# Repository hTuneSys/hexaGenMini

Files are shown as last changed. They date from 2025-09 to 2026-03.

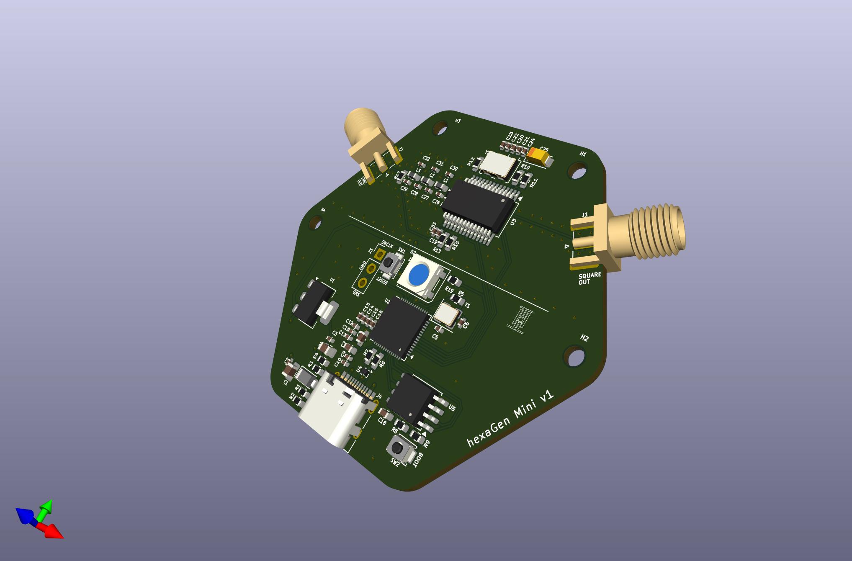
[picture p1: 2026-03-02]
hardware/hexaGenMini-v1/hexaGenMini-v1-2.jpg

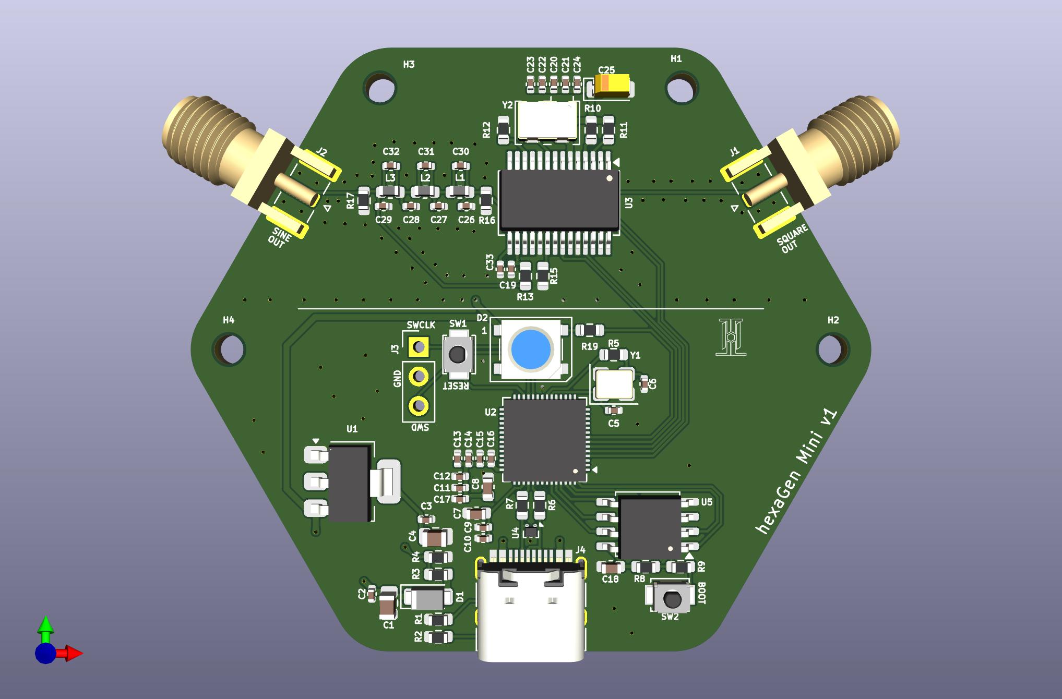
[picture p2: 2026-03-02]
hardware/hexaGenMini-v1/hexaGenMini-v1-1.jpg

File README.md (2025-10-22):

<!--
SPDX-FileCopyrightText: 2025 hexaTune LLC
SPDX-License-Identifier: MIT
-->

# 🎛️ hexaGenMini






**hexaGenMini** is a compact, USB-powered signal generator designed for music synthesis and electronic experimentation. Built on the Raspberry Pi Pico (RP2040), it features Direct Digital Synthesis (DDS) for precise frequency generation, RGB status indication, and USB MIDI control via AT commands.

Developed by **hexaTune LLC** and the **hexaTeam**, led by **Husamettin ARABACI**.

## ✨ Features

- **Precise Frequency Generation**: AD985x DDS chip supporting frequencies up to 125MHz
- **USB MIDI Control**: Send AT commands via MIDI SysEx for remote control
- **RGB Status LED**: Visual feedback for device state and DDS availability
- **Firmware Updates**: Built-in BOOTSEL mode for easy firmware flashing
- **Cross-Platform**: Works with any USB MIDI-compatible host
- **Mobile App**: Control via dedicated iOS/Android app ([hexaGenApp](https://github.com/hTuneSys/hexaGenApp))
- **Open Source**: Fully open hardware and software under MIT license

## 📱 Mobile App

Control your hexaGenMini wirelessly with our companion mobile app:

- **iOS & Android Support**
- **Real-time Frequency Control**
- **Preset Management**
- **Visual Waveform Display**




**Source Code**: [hTuneSys/hexaGenApp](https://github.com/hTuneSys/hexaGenApp)

## 🚀 Quick Start

1. **Connect** your hexaGenMini via USB
2. **Flash Firmware**:
   ```bash
   cd firmware
   cargo run
   ```
3. **Send AT Commands** via MIDI SysEx:
   ```
   AT+FREQ=1#1000000#1000  # Set 1MHz for 1 second
   AT+SETRGB=2#255#0#128   # Set LED to purple
   ```

## 📦 Installation

### Prerequisites

- **Rust** (1.86.0+): [Install rustup](https://rustup.rs/)
- **picotool**: For flashing RP2040
- **Node.js & pnpm**: For development tools
- **KiCad** (optional): For hardware modifications
- **FreeCAD** (optional): For enclosure modifications

### Setup

```bash
# Clone repository
git clone https://github.com/hTuneSys/hexaGenMini.git
cd hexaGenMini

# Install development dependencies
pnpm install
pnpm prepare  # Setup husky pre-commit hooks

# Install Rust targets
rustup target add thumbv6m-none-eabi
```

### Flashing Firmware

```bash
cd firmware
cargo run
```

Put your device in BOOTSEL mode (hold BOOTSEL while plugging in) when prompted.

## 🎯 Usage

### AT Command Protocol

hexaGenMini uses AT commands sent via MIDI SysEx messages:

#### Supported Commands

- `AT+VERSION?` - Get firmware version
- `AT+SETRGB=<ID>#<R>#<G>#<B>` - Set RGB LED color
- `AT+FREQ=<ID>#<FREQ>#<TIME_MS>` - Generate frequency with dwell time
- `AT+RESET=<ID>` - System reset
- `AT+FWUPDATE=<ID>` - Enter firmware update mode

#### Example Usage

```bash
# Query version
AT+VERSION?

# Set frequency to 440Hz for 5 seconds
AT+FREQ=1#440#5000

# Set LED to red
AT+SETRGB=2#255#0#0
```

### Hardware Connections

- **USB**: Power and MIDI communication
- **SMA Output**: DDS signal output
- **RGB LED**: Status indication
- **BOOTSEL**: Firmware update mode

## 🏗️ Architecture

The firmware is built with Rust and Embassy, running concurrent async tasks:

- **USB Task**: MIDI communication handling
- **AT Dispatcher**: Command parsing and routing
- **DDS Task**: Frequency generation control
- **RGB Task**: LED management
- **Main Loop**: Status monitoring

For detailed architecture information, see [docs/ARCHITECTURE.md](docs/ARCHITECTURE.md).

## 📁 Project Structure

```
hexaGenMini/
├── firmware/          # Rust firmware (Embassy framework)
├── hardware/          # KiCad PCB designs
├── mechanic/          # FreeCAD enclosure designs
├── docs/             # Documentation
├── .github/          # CI/CD workflows
└── README.md
```

## 🤝 Contributing

We welcome contributions! Please see our [Contributing Guide](docs/CONTRIBUTING.md) for details.

### Development Workflow

1. Fork the repository
2. Create a feature branch from `develop`
3. Make your changes
4. Submit a pull request
5. Follow conventional commit format

### Areas for Contribution

- Firmware enhancements
- Hardware improvements
- Documentation
- Mobile app features
- Testing and CI/CD

## 📄 Documentation

- [Getting Started](docs/GETTING_STARTED.md) - Setup guide
- [Architecture](docs/ARCHITECTURE.md) - System design
- [Project Structure](docs/PROJECT_STRUCTURE.md) - Repository overview
- [Contributing](docs/CONTRIBUTING.md) - How to contribute
- [FAQ](docs/FAQ.md) - Common questions

## 📜 License

This project is licensed under the MIT License - see the [LICENSE](LICENSE) file for details.

## 📞 Contact

- **Website**: [hexatune.com](https://hexatune.com)
- **Email**: [info@hexatune.com](mailto:info@hexatune.com)
- **GitHub**: [hTuneSys](https://github.com/hTuneSys)
- **Issues**: [GitHub Issues](https://github.com/hTuneSys/hexaGenMini/issues)

## 🙏 Acknowledgments

Built with ❤️ by the hexaTeam at hexaTune LLC.

Special thanks to the Rust embedded community and Embassy framework developers.

---

**hexaGenMini** - Precision meets portability in signal generation.

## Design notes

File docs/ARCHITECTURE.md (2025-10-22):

<!--
SPDX-FileCopyrightText: 2025 hexaTune LLC
SPDX-License-Identifier: MIT
-->

# 🏗️ hexaGenMini Architecture

---

## 📬 Questions?

Contact the team at **[info@hexatune.com](mailto:info@hexatune.com)** or open an issue.

---

Built by [hexaTune LLC](https://hexatune.com) · GitHub: [hTuneSys/hexaGenMini](https://github.com/hTuneSys/hexaGenMini) · License: [MIT](https://opensource.org/license/mit/)

---

## Overview

hexaGenMini is a compact signal generator device based on the Raspberry Pi Pico (RP2040) microcontroller. It features a Direct Digital Synthesis (DDS) module for generating precise waveforms, an RGB LED for status indication, and USB MIDI communication for control. The device is designed for integration into music synthesis setups, providing frequency generation capabilities via AT command protocol over MIDI SysEx messages.

## System Architecture

The firmware is written in Rust using the Embassy framework for embedded async programming. It consists of several modules running as concurrent tasks on the RP2040's dual cores:

- **USB Module**: Handles USB MIDI communication
- **AT Command Module**: Parses and dispatches AT commands
- **DDS Module**: Controls the AD985x DDS chip for frequency generation
- **RGB Module**: Manages the WS2812 RGB LED
- **Channel Manager**: Facilitates inter-task communication via async channels

### Core 0 Tasks
- USB Device Task
- USB IO Task
- AT Task
- RGB Task
- Main Loop Task

### Core 1 Tasks
- DDS Task

## System Flow

1. **Initialization**: The main function initializes peripherals, sets up channels, and spawns tasks on both cores.

2. **USB Communication**: USB IO task listens for incoming MIDI packets containing SysEx messages.

3. **AT Command Parsing**: Received SysEx payloads are parsed into AT commands.

4. **Command Dispatch**: The AT dispatcher routes commands to appropriate handlers based on the command name.

5. **Handler Execution**: Handlers perform actions like setting frequency, changing LED color, or triggering firmware updates.

6. **Response Generation**: Results are compiled back into AT response format and sent via USB MIDI.

## AT Command Structure

AT commands follow a specific format for communication with the device:

### Command Format
```
AT+<COMMAND>=<ID>#<PARAM1>#<PARAM2>#...
```

### Query Format
```
AT+<COMMAND>?
```

### Response Format
```
AT+<RESPONSE>=<ID>#<PARAM1>#<PARAM2>#...
```

### Supported Commands

#### VERSION
- **Query**: `AT+VERSION?`
- **Response**: `AT+VERSION=0#v1.0.0`
- **Description**: Returns the firmware version

#### SETRGB
- **Command**: `AT+SETRGB=<ID>#<R>#<G>#<B>`
- **Response**: `AT+DONE=<ID>`
- **Description**: Sets the RGB LED color (R, G, B values 0-255)
- **Example**: `AT+SETRGB=123#255#0#128`

#### RESET
- **Command**: `AT+RESET=<ID>`
- **Description**: Performs a system reset
- **Note**: No response as device resets

#### FWUPDATE
- **Command**: `AT+FWUPDATE=<ID>`
- **Description**: Enters BOOTSEL mode for firmware update
- **Note**: No response as device enters bootloader

#### FREQ
- **Command**: `AT+FREQ=<ID>#<FREQUENCY>#<TIME_MS>`
- **Response**: `AT+DONE=<ID>` or `AT+ERROR=<ID>#<ERROR_CODE>`
- **Description**: Sets DDS frequency with dwell time
- **Parameters**:
  - FREQUENCY: Frequency in Hz (u32)
  - TIME_MS: Dwell time in milliseconds (u32)
- **Example**: `AT+FREQ=456#1000000#5000`

### Error Codes
- E001001: Invalid command
- E001002: DDS busy
- E001003: Invalid UTF-8
- E001004: Invalid SysEx
- E001005: Invalid data length
- E001006: Parameter count error
- E001007: Parameter value error
- E001008: Not a query
- E001009: Unknown command

## Communication Protocol

Commands are sent as MIDI SysEx messages over USB MIDI:

- **SysEx Start**: 0xF0
- **Payload**: UTF-8 encoded AT command string
- **SysEx End**: 0xF7

The USB MIDI implementation uses standard MIDI packet formats for SysEx transmission.

## Hardware Interfaces

- **USB**: Full-speed USB 2.0 for MIDI communication
- **DDS**: AD985x controlled via GPIO bit-banging
- **RGB LED**: WS2812 controlled via PIO
- **Status LED**: Onboard LED for system status

## Task Communication

Inter-task communication uses Embassy async channels with a capacity of 16 messages per channel. The ChannelManager provides typed access to senders and receivers for each module.

## Configuration

System configuration is managed through constants in `hexa_config` module, including version information and DDS availability status.

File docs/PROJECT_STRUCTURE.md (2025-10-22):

<!--
SPDX-FileCopyrightText: 2025 hexaTune LLC
SPDX-License-Identifier: MIT
-->

# 📁 Project Structure: `hexaGenMini`

This document outlines the organization of the hexaGenMini project repository.

## Root Directory

- `.github/`: GitHub workflows, issue templates, and configuration
- `.husky/`: Git hooks for commit linting
- `docs/`: Documentation files
- `firmware/`: Embedded firmware source code (Rust)
- `hardware/`: PCB design files (KiCad)
- `mechanic/`: Mechanical design files (FreeCAD)
- `LICENSE`: MIT license
- `README.md`: Project overview
- `package.json` & `pnpm-lock.yaml`: Node.js dependencies for tooling

## Firmware Directory (`firmware/`)

The firmware is written in Rust using the Embassy framework for the RP2040 microcontroller.

- `src/`: Source code
  - `main.rs`: Application entry point and task initialization
  - `at/`: AT command parsing and handling
  - `channel/`: Inter-task communication channels
  - `dds/`: Direct Digital Synthesis (AD985x) control
  - `error/`: Error definitions
  - `hexa_config/`: Configuration constants
  - `rgb/`: RGB LED control
  - `sysex/`: MIDI SysEx message handling
  - `usb/`: USB MIDI communication
- `build.rs`: Build script for memory layout
- `Cargo.toml`: Rust dependencies and build configuration
- `memory.x`: Linker memory layout

## Hardware Directory (`hardware/`)

PCB designs created with KiCad.

- `hexaGenMini-v1/`: Main PCB design
  - `fabrication_output/`: Manufacturing files
    - `bom/`: Bill of Materials
    - `gerber/`: Gerber files for PCB fabrication
    - `pnp/`: Pick and place files
  - `*.kicad_*`: KiCad project files
  - `PCB_Library.pretty/`: Custom KiCad footprints
  - `SCH_Library.kicad_sym`: Custom KiCad symbols

## Mechanic Directory (`mechanic/`)

Mechanical designs for the product enclosure, created with FreeCAD.

- `Bottom.FCStd`: Bottom case design
- `PcbBoard.FCStd`: PCB mounting design
- `PcbBoard-Body.dxf`: 2D export for manufacturing

## Documentation (`docs/`)

- `ARCHITECTURE.md`: System architecture and AT command protocol
- `BRANCH_STRATEGY.md`: Git branching guidelines
- `BRANDING.md`: Branding guidelines
- `COMMIT_STRATEGY.md`: Commit message conventions
- `COMMUNITY.md`: Community guidelines
- `CONFIGURATION.md`: Configuration instructions
- `CONTACT.md`: Contact information
- `CONTRIBUTING.md`: Contribution guidelines
- `DEVELOPMENT_GUIDE.md`: Development setup
- `FAQ.md`: Frequently asked questions
- `GETTING_STARTED.md`: Quick start guide
- `LABELLING_STRATEGY.md`: Issue labeling
- `PR_STRATEGY.md`: Pull request guidelines
- `PROJECT_BOARD.md`: Project management
- `PROJECT_STRUCTURE.md`: This file
- `SECURITY.md`: Security policy
- `STYLE_GUIDE.md`: Code style guidelines
- `SUMMARY.md`: Project summary
- `SUPPORT.md`: Support information

## Build and Development

- Firmware: Built with Cargo (Rust toolchain)
- Hardware: Fabricated using standard PCB processes
- Mechanics: Manufactured using 3D printing or CNC

For detailed setup instructions, see `docs/DEVELOPMENT_GUIDE.md`.

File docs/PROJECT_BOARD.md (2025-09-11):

<!--
SPDX-FileCopyrightText: 2025 hexaTune LLC
SPDX-License-Identifier: MIT
-->

# PROJECT_BOARD.md

This document describes the structure and usage of the hexaGenMini GitHub Project Board used for tracking issues, workflows, and development progress.

---

## 🧭 Board Overview

The hexaGenMini project board is organized using GitHub Projects (v2) with the following columns:

1. **Inbox** – New issues or ideas needing triage  
2. **Backlog** – Approved but not yet scheduled items  
3. **In Progress** – Actively being worked on  
4. **In Review** – Awaiting PR review or discussion  
5. **Blocked** – Work paused due to dependencies  
6. **Done** – Completed tasks  
7. **Closed** – Rejected or archived items  

---

## 🏷️ Label Integration

Cards are automatically categorized using GitHub Labels, such as:

- `type: bug`, `type: feature`, `type: question`, etc.
- `status: in progress`, `status: review`, `status: blocked`
- `priority: high`, `priority: low`

These labels help sort and filter cards efficiently.

---

## 🔄 Workflow Rules

- Issues moved to **In Progress** must be assigned to a contributor.
- Pull Requests are linked to issues and automatically update board state.
- The **In Review** column is for PRs with open reviews.
- Cards in **Done** are periodically cleaned up to **Closed**.

---

## 🔧 Automation

GitHub Actions and project workflows automate the board:

- Auto-assign labels on issue creation
- Auto-move cards based on PR status
- Auto-close completed issues when PRs are merged

---

## 🔗 Access the Board

Visit the live project board here:  
➡️ [BOARD](https://github.com/orgs/hTuneSys/projects/16/views/1)

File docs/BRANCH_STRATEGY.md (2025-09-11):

<!--
SPDX-FileCopyrightText: 2025 hexaTune LLC
SPDX-License-Identifier: MIT
-->

# 📚 Branching Strategy for hexaGenMini

This project follows a structured, scalable branching model inspired by GitHub Flow, Gitflow, and real-world enterprise project practices.  
All contributors are expected to adhere to these rules for consistent development and stable releases.

---

## 🔱 Branch Layers and Types

| Branch | Purpose | Allowed Types (Prefix) |
|---|---|---|
| `main` | Production branch. All official releases are tagged here. | N/A (protected branch) |
| `release/x.y` | Pre-release stabilization, final QA and testing. | N/A (protected branch) |
| `develop` | Integration branch for ongoing feature and fix PRs. | N/A (protected branch) |
| `feature/xyz` | Development of new features. | `feat/` |
| `fix/bug-id` | Bug fixes and patches. | `fix/` |
| `chore/*` | Routine tasks, maintenance, housekeeping. | `chore/` |
| `refactor/*` | Code refactoring without feature or bug changes. | `refactor/` |
| `test/*` | Test additions and modifications. | `test/` |
| `docs/*` | Documentation improvements and additions. | `docs/` |
| `ci/*` | Continuous Integration and automation scripts. | `ci/` |
| `perf/*` | Performance improvements. | `perf/` |
| `build/*` | Build-related changes (packaging, dependencies). | `build/` |
| `hotfix/*` | Emergency fixes applied directly on `main`. | `hotfix/` |
| `style/*` | Code style and formatting changes. | `style/` |

---

## 🔄 Pull Request Flow

### 🔁 For Contributors

- All PRs **must be based on `develop`** unless hotfixing `main`.
- Branch names should start with one of the allowed prefixes from the table above.
- PR titles must follow [Conventional Commits](https://www.conventionalcommits.org/) format.
- Keep your PR focused and small for easier review.

### ✅ Merge Rules

- `feature/*`, `fix/*`, `chore/*`, `refactor/*`, `test/*`, `docs/*`, `ci/*`, `perf/*`, `build/*`, `style/*` → merge into `develop` after review & CI pass.
- `develop` → `release/x.y` at sprint end for release prep.
- `release/x.y` → `main` after QA and approval.
- `hotfix/*` → `main` → `develop` immediately.

---

## 🔐 Branch Protection Rules

| Branch | Protection |
|---|---|
| `main` | Required PR, review, status checks |
| `release/*`  | Only maintainers can merge |
| `develop` | PR required, minimum 1 review |
| others | No restriction, delete after merge |

---

## 🗓️ Merge Schedule

| Action | Frequency |
|---|---|
| `feature/*` → `develop` | As soon as ready |
| `develop` → `release/x.y` | Weekly or per sprint |
| `release/x.y` → `main` | After QA/approval |
| `hotfix/*` → `main` | Immediately if needed|

---

## 🧹 Cleanup Policy

- Merged feature, fix, chore, refactor, test, docs, ci, perf, build, style branches **must be deleted immediately**.
- `release/*` branches are deleted **after tagging**.
- `hotfix/*` branches are merged and deleted **immediately**.
- Consider automating branch deletion using GitHub Settings or scripts.

---

## 📈 Do’s and Don’ts

### Do

- Use **clear, descriptive branch names** with allowed prefixes.
- Open **small, focused PRs** for faster review.
- Follow **commit and PR title conventions**.
- Sync with `develop` frequently.

### Don’t

- Push large or unrelated changes in a single PR.
- Merge into `main` or `release/*` without approval.
- Use branch names outside the approved prefixes.
- Forget to delete branches after merge.

---

## 🔄 PR Flow Diagram (Textual)

```text
feature/*, fix/*, chore/* ... -> develop -> release/x.y -> main
                                ↑               ↑
                           hotfix/* ------------|
```

---

## 📬 Questions?

If you have questions or need help, open a discussion at:  
[https://github.com/hTuneSys/hexaGenMini/discussions](https://github.com/hTuneSys/hexaGenMini/discussions)

---

> Maintained by @husamettinarabaci · hexaTune LLC

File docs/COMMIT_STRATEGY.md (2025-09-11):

<!--
SPDX-FileCopyrightText: 2025 hexaTune LLC
SPDX-License-Identifier: MIT
-->

# COMMIT_STRATEGY.md

## 🔖 Commit Message Strategy for hexaGenMini

To ensure consistent and readable commit messages across the project, **hexaGenMini** enforces the use of a standardized commit format and a predefined set of commit types.

---

## ✅ Commit Format

Each commit message must follow this format:

```text
<type>(optional-scope): <short summary>
```

---

## 🧩 Supported Commit Types with Examples

### 1. **feat** — A new feature for the user or system

```text
feat: add dark mode support
feat(auth): implement token refresh logic
feat(ui): create responsive navbar component
```

### 2. **fix** — A bug fix that impacts user behavior

```text
fix: resolve crash on empty input
fix(api): correct 500 error on login
fix(auth): fix token expiration handling
```

### 3. **docs** — Changes to documentation only

```text
docs: update README with setup instructions
docs(contributing): add issue template section
docs(api): fix typo in endpoint descriptions
```

### 4. **style** — Code style changes (formatting, white-space, etc.)

```text
style: reformat code with Prettier
style(auth): fix indentation
style: remove unnecessary semicolons
```

### 5. **refactor** — Code changes that neither fix a bug nor add a feature

```text
refactor: simplify state management logic
refactor(db): reorganize model definitions
refactor: extract common utility functions
```

### 6. **perf** — A code change that improves performance

```text
perf(api): cache frequently accessed data
perf: reduce image load time by optimizing assets
perf(ui): memoize expensive component renders
```

### 7. **test** — Adding or updating tests

```text
test: add unit tests for user service
test(auth): improve test coverage for login flow
test: mock API for integration tests
```

### 8. **chore** — Routine tasks like build process, dependencies

```text
chore: update project dependencies
chore(lint): add eslint config
chore: clean up temporary files
```

### 9. **ci** — CI/CD configuration and scripts

```text
ci: add GitHub Actions workflow
ci: fix broken CI script
ci: integrate code coverage reporting
```

### 10. **build** — Changes to build system or dependencies

```text
build: switch to Vite from Webpack
build: update TypeScript compiler settings
build: configure output directory for deployment
```

### 11. **release** — Versioning or release-related changes

```text
release: bump version to 1.2.0
release: update changelog for new release
release: prepare hotfix 1.2.1
```

### 12. **hotfix** — Urgent fixes, often related to production issues

```text
hotfix: fix production crash on launch
hotfix(auth): patch login issue in prod
hotfix(api): temporary rollback for breaking endpoint
```

---

## 🚫 What to Avoid

- Do **not** use generic commit messages like "update" or "fix bug".
- Do **not** push without proper commit type and summary.
- Do **not** include long descriptions in the title.

---

## 🛠 Tools & Automation

This strategy is supported by tools such as:

- **commitlint** for linting commit messages.
- **Husky** to enforce commit rules pre-commit.
- **Semantic Release** (optional) for automated versioning based on commit messages.

---

## 💡 Tips

- Use imperative mood: "add" not "added" or "adds".
- Keep summary under 72 characters.
- Reference issues when necessary (e.g., `fix: resolve #42`).

---

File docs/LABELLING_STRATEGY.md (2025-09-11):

<!--
SPDX-FileCopyrightText: 2025 hexaTune LLC
SPDX-License-Identifier: MIT
-->

# LABELLING_STRATEGY.md

This document defines the complete, system-approved label taxonomy used in the hexaGenMini GitHub repository. These labels help organize issues and pull requests for better triage, automation, and collaboration.

---

## 🧭 Meta Labels

- `default:unclassified` – No specific category matched this PR or file path

---

## 🧑‍💻 Contribution Labels

- `good first issue` – Good entry point for contributors
- `help wanted` – Contributions welcome

---

## 🧩 Module Labels

- `module:firmware` – Effected firmware code
- `module:hardware` – Effected hardware design
- `module:mechanic` – Effected mechanical design
- `module:docs` – Documentation tasks
- `module:cli` – CLI tools

---

## 📊 Priority Labels

- `priority:high` – Urgent and critical tasks
- `priority:medium` – Normal importance
- `priority:low` – Can wait

---

## 🔁 Status Labels

- `status:blocked` – Blocked by another issue or PR
- `status:needs-review` – Awaiting code review
- `status:needs-spec` – Needs specification or detail
- `status:waiting-feedback` – Awaiting external feedback

---

## 🏷️ Type Labels

- `type:bug` – A defect or malfunction
- `type:ci` – CI/CD workflows and automation tasks
- `type:compliance` – Standards, audits, and certification checks (e.g., OpenSSF)
- `type:doc` – Documentation content
- `type:enhancement` – Enhancement of existing functionality
- `type:feature` – New feature or capability
- `type:infra` – Infrastructure, CI/CD, build system
- `type:legal` – Legal compliance tasks like DCO/CLA
- `type:refactor` – Code restructuring with no behavior change
- `type:release` – Tasks related to versioning, packaging, and publishing
- `type:security` – Vulnerability or security concern
- `type:test` – Test writing or coverage

---

## ✅ Best Practices

- Use exactly one `type:` label per issue/PR
- Use at most one `priority:` label
- Assign `status:` labels to track board movement
- Apply `module:` labels to indicate affected areas
- `default:unclassified` should be removed once other labels are assigned

---

This standardized labeling system enables GitHub automation, PR triage, and progress tracking across the hexaGenMini project.

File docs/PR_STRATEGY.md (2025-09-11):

<!--
SPDX-FileCopyrightText: 2025 hexaTune LLC
SPDX-License-Identifier: MIT
-->

# PR_STRATEGY.md

This document outlines the strategy, conventions, and rules for managing Pull Requests (PRs) in the hexaGenMini project.

---

## ✅ PR Title Convention

All PR titles must follow one of the 12 supported types:

- `feat`: New feature
- `fix`: Bug fix
- `docs`: Documentation only changes
- `style`: Code style, formatting (no logic change)
- `refactor`: Code refactoring (no feature change)
- `perf`: Performance improvements
- `test`: Adding or modifying tests
- `ci`: Changes to CI/CD configuration
- `build`: Build system or dependencies
- `chore`: Maintenance or tooling
- `release`: Versioning, changelog updates
- `hotfix`: Emergency fix for critical issues

**Example**:

```bash
feat: add user authentication module
```

---

## 📋 PR Checklist

Every PR must fulfill the following requirements:

- [ ] Clear and descriptive title using a valid PR type
- [ ] Related issue linked (if applicable)
- [ ] Description explains the context and purpose
- [ ] No unrelated changes or mixed concerns
- [ ] All checks pass (CI, lint, test)
- [ ] Reviewers assigned
- [ ] Labels applied

---

## 🛠️ PR Workflow

1. **Create a feature/fix branch**  
   Use a semantic branch name like:  
   `feat/login-form`, `fix/null-crash`, `docs/api-guide`

2. **Open a Draft PR**  
   Start as draft if it's a work-in-progress

3. **Update the PR as work progresses**  
   Keep commits clean and meaningful

4. **Mark as Ready for Review**  
   Request review from maintainers

5. **Address Review Comments**  
   Resolve all conversations before merge

---

## 🔒 Protection Rules

- PRs targeting protected branches (e.g., `main`, `release`) must:
  - Pass all status checks
  - Be reviewed by at least 1 maintainer
  - Use a valid PR title type

---

## ⛔ What to Avoid

- PRs with vague titles like “update” or “fix stuff”
- Mixing unrelated concerns in a single PR
- Skipping the review process or checks

---

Adhering to this PR strategy ensures clean history, traceable changes, and predictable releases.

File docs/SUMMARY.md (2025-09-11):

<!--
SPDX-FileCopyrightText: 2025 hexaTune LLC
SPDX-License-Identifier: MIT
-->

# SUMMARY.md

Welcome to the hexaGenMini project documentation hub. This file summarizes the structure and purpose of each document found in the `docs/` directory.

---

## 🧭 Project Strategy & Structure

- [SUMMARY](SUMMARY.md) – High-level summary of all documentation files
- [ARCHITECTURE](ARCHITECTURE.md) – System design and internal architecture

---

## 🛠 Contribution & Workflow

- [CONTRIBUTING](CONTRIBUTING.md) – Guidelines for contributing (issues, PRs, code)
- [CODE_OF_CONDUCT](CODE_OF_CONDUCT.md) – Community behavior rules
- [PR_STRATEGY](PR_STRATEGY.md) – Rules for naming, reviewing, and merging PRs
- [COMMIT_STRATEGY](COMMIT_STRATEGY.md) – Commit message types and best practices
- [BRANCH_STRATEGY](BRANCH_STRATEGY.md) – Naming and usage rules for git branches
- [LABELLING_STRATEGY](LABELLING_STRATEGY.md) – System of issue/PR labels and their purpose
- [PROJECT_STRUCTURE](PROJECT_STRUCTURE.md) – Directory structure and module breakdown

---

## 👨‍💻 Developer Tools

- [CONFIGURATION](CONFIGURATION.md) – Runtime and environment settings
- [STYLE_GUIDE](STYLE_GUIDE.md) – Coding conventions and formatting rules
- [GETTING_STARTED](GETTING_STARTED.md) – Setup instructions for new devs
- [DEVELOPMENT_GUIDE](DEVELOPMENT_GUIDE.md) – In-depth dev guide
- [FAQ](FAQ.md) – Frequently asked questions

---

## 🤝 Community & Support

- [COMMUNITY](COMMUNITY.md) – Community engagement and interaction rules
- [CONTACT](CONTACT.md) – How to reach maintainers or report issues
- [SUPPORT](SUPPORT.md) – How to get help and where to ask questions

---

## 🌐 Branding & Website

- [BRANDING](BRANDING.md) – Visual identity and logo usage
- [CNAME](CNAME) – Custom domain for GitHub Pages
- [Web Site](https://hexatune.com) – Landing page of documentation site

---

This summary will help you navigate the docs efficiently and understand their purpose in the project lifecycle.

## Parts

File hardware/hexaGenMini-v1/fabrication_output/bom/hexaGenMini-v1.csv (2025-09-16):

Reference | Qty | Value | MFR | MPN | LCSPN | DNP | Exclude from BOM | Exclude from Board | Footprint | Datasheet
H1,H2,H3,H4 | 4 | MountingHole |  |  |  |  | Excluded from BOM |  | MountingHole:MountingHole_2.5mm | ~
J3 | 1 | Conn_01x03_Pin |  |  |  |  | Excluded from BOM |  | Connector_PinHeader_2.54mm:PinHeader_1x03_P2.54mm_Vertical | ~
Y2 | 1 | XO53 | ABRACON | ASFL1-125.000MHZ-LC-T | C17447576 |  |  |  | Oscillator:Oscillator_SMD_EuroQuartz_XO53-4Pin_5.0x3.2mm | http://cdn-reichelt.de/documents/datenblatt/B400/XO53.pdf
U3 | 1 | AD9850 | ADI | AD9850BRSZ | C18731 |  |  |  | Package_SO:SSOP-28_5.3x10.2mm_P0.65mm | https://www.analog.com/media/en/technical-documentation/data-sheets/AD9850.pdf
Y1 | 1 | 12MHz 18pF | EPSON | Q22FA23V00418 | C91749 |  |  |  | Crystal:Crystal_SMD_3225-4Pin_3.2x2.5mm | ~
R1,R2 | 2 | 5.1kΩ ±1% 100mW | FOJAN | FRC0603F5101TS | C2907044 |  |  |  | Resistor_SMD:R_0603_1608Metric | ~
R3 | 1 | 5.6kΩ ±1% 100mW | FOJAN | FRC0603F5601TS | C2907046 |  |  |  | Resistor_SMD:R_0603_1608Metric | ~
R6,R7 | 2 | 27Ω ±1% 100mW | FOJAN | FRC0603F27R0TS | C2907021 |  |  |  | Resistor_SMD:R_0603_1608Metric | ~
J4 | 1 | USB_C_Receptacle_USB2.0_16P | hanxia | HX-TYPE-C 16P 180 LT H10.0 USB 2.0 TYPE-C | C49261569 |  |  |  | Connector_USB:USB_C_Receptacle_HRO_TYPE-C-31-M-12 | https://www.usb.org/sites/default/files/documents/usb_type-c.zip
C25 | 1 | TANT 10uF ±20% 20V | KEMET | T491A106M020AT | C117023 |  |  |  | Capacitor_Tantalum_SMD:CP_EIA-3216-18_Kemet-A | ~
C19,C33 | 2 | CER 470pF 50V C0G | muRata | GRM1555C1H471JA01D | C76971 |  |  |  | Capacitor_SMD:C_0402_1005Metric | ~
C26,C28,C29 | 3 | CER 22pF 50V C0G | muRata | GRM1555C1H220JA01D | C76960 |  |  |  | Capacitor_SMD:C_0402_1005Metric | ~
C30 | 1 | CER 1pF 50V C0G | muRata | GJM1555C1H1R0BB01D | C76898 |  |  |  | Capacitor_SMD:C_0402_1005Metric | ~
C32 | 1 | CER 4.7pF 50V C0G | muRata | GJM1555C1H4R7BB01D | C161327 |  |  |  | Capacitor_SMD:C_0402_1005Metric | ~
L1 | 1 | 470nH 500mA 450mΩ | muRata | LQW18CNR47J00D | C341701 |  |  |  | Inductor_SMD:L_0603_1608Metric | ~
L2,L3 | 2 | 390nH 80mA 6.2Ω | muRata | LQW18ANR39G00D | C98095 |  |  |  | Inductor_SMD:L_0603_1608Metric | ~
SW1,SW2 | 2 | TACTILE SPST | OMRON | B3U-1000P | C231329 |  |  |  | Button_Switch_SMD:SW_SPST_B3U-1000P | ~
U2 | 1 | RP2040 | Raspberry Pi | RP2040 | C2040 |  |  |  | Package_DFN_QFN:QFN-56-1EP_7x7mm_P0.4mm_EP3.2x3.2mm | https://datasheets.raspberrypi.com/rp2040/rp2040-datasheet.pdf
C1,C4 | 2 | CER 10uF 25V X5R | Samsung Electro-Mechanics | CL21A106KAYNNNE | C15850 |  |  |  | Capacitor_SMD:C_0805_2012Metric | ~
C2,C3,C9,C10,C11,C12,C13,C14,C15,C16,C17,C20,C21,C22,C23,C24 | 16 | CER 100nF 16V X7R | Samsung Electro-Mechanics | CL05B104KO5NNNC | C1525 |  |  |  | Capacitor_SMD:C_0402_1005Metric | ~
C7,C8,C18 | 3 | CER 1uF 50V X5R | Samsung Electro-Mechanics | CL10A105KB8NNNC | C15849 |  |  |  | Capacitor_SMD:C_0603_1608Metric | ~
C27 | 1 | CER 33pF 50V C0G | Samsung Electro-Mechanics | CL05C330JB5NNNC | C70465 |  |  |  | Capacitor_SMD:C_0402_1005Metric | ~
J1,J2 | 2 | RCPT SMA 50Ω | Samtec | SMA-J-P-H-ST-EM1 | C5199907 |  |  |  | Connector_Coaxial:SMA_Samtec_SMA-J-P-H-ST-EM1_EdgeMount | ~
U1 | 1 | AMS1117-3.3 | Slkor | AMS1117-3.3 | C426566 |  |  |  | Package_TO_SOT_SMD:SOT-223-3_TabPin2 | http://www.advanced-monolithic.com/pdf/ds1117.pdf
U4 | 1 | TVS DIODE 5.5VWM 18VC | TECH PUBLIC | TPD2EUSB30DRTR | C5182099 |  |  |  | Package_TO_SOT_SMD:Texas_DRT-3 | http://www.ti.com/lit/ds/symlink/tpd2eusb30a.pdf
R4,R8,R11 | 3 | 10kΩ ±1% 100mW | UNI-ROYAL | 0603WAF1002T5E | C25804 |  |  |  | Resistor_SMD:R_0603_1608Metric | ~
R16,R17 | 2 | 200Ω ±1% 100mW | UNI-ROYAL | 0603WAF2000T5E | C8218 |  |  |  | Resistor_SMD:R_0603_1608Metric | ~
R19 | 1 | 330Ω ±1% 100mW | UNI-ROYAL | 0603WAF3300T5E | C23138 |  |  |  | Resistor_SMD:R_0603_1608Metric | ~
D1 | 1 | ESD DIODE 5VWM 9.2VC | VISHAY | SMF5V0A-E3-08 | C1972946 |  |  |  | Diode_SMD:D_SMF | https://www.vishay.com/doc?85881
U5 | 1 | W25Q128JVS | Winbond | W25Q128JVSIQ | C97521 |  |  |  | Package_SO:SOIC-8_5.3x5.3mm_P1.27mm | https://www.winbond.com/resource-files/w25q128jv_dtr%20revc%2003272018%20plus.pdf
D2 | 1 | WS2812B | Worldsemi | WS2812B-B/T | C2761795 |  |  |  | LED_SMD:LED_WS2812B_PLCC4_5.0x5.0mm_P3.2mm | https://cdn-shop.adafruit.com/datasheets/WS2812B.pdf
C5,C6 | 2 | CER 27pF 50V NP0 | YAGEO | CC0402JRNPO9BN270 | C107002 |  |  |  | Capacitor_SMD:C_0402_1005Metric | ~
C31 | 1 | CER 5.6pF 50V NP0 | YAGEO | CC0402BRNPO9BN5R6 | C505468 |  |  |  | Capacitor_SMD:C_0402_1005Metric | ~
R5,R9,R10 | 3 | 1kΩ ±1% 100mW | YAGEO | RC0603FR-071KL | C22548 |  |  |  | Resistor_SMD:R_0603_1608Metric | ~
R12 | 1 | 3.9kΩ ±1% 100mW | YAGEO | RC0603FR-073K9L | C114616 |  |  |  | Resistor_SMD:R_0603_1608Metric | ~
R13,R15 | 2 | 100Ω ±1% 100mW | YAGEO | RC0603FR-07100RL | C105588 |  |  |  | Resistor_SMD:R_0603_1608Metric | ~

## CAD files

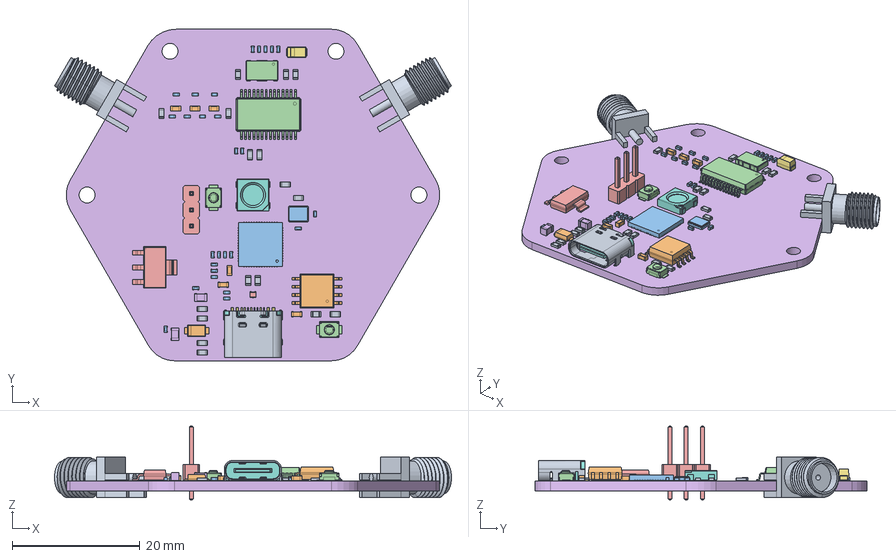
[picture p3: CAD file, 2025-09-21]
hardware/hexaGenMini-v1/hexaGenMini-v1.step
62.2 x 52.0 x 11.5 mm
R_0603_1608Metric x 17
C_0603_1608Metric x 3
C_0402_1005Metric x 27
SW_SPST_B3U-1000P x 2
PinHeader_1x03_P2.54mm_Vertical
C_0805_2012Metric x 2
CP_EIA-3216-18_Kemet-A
LED_WS2812B_PLCC4_5.0x5.0mm_P3.2mm
SMA_Samtec_SMA-J-P-H-ST-EM1_EdgeMount x 2
SOIC-8_5.3x5.3mm_P1.27mm
L_0603_1608Metric x 3
Crystal_SMD_3225-4Pin_3.2x2.5mm
Oscillator_SMD_EuroQuartz_XO53-4Pin_5.0x3.2mm
SOT-223
ConPins
PcbPins
Mold
Frame
D_SMF
QFN-56-1EP_7x7mm_P0.4mm_EP3.2x3.2mm
SSOP-28_5.3x10.2mm_P0.65mm
Texas_DRT-3
hexaGenMini-v1_PCB

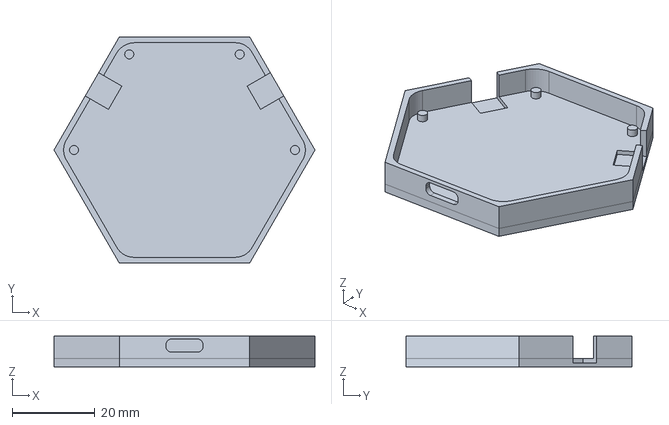
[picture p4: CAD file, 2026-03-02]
mechanic/Bottom.FCStd
63.2 x 54.7 x 7.50 mm

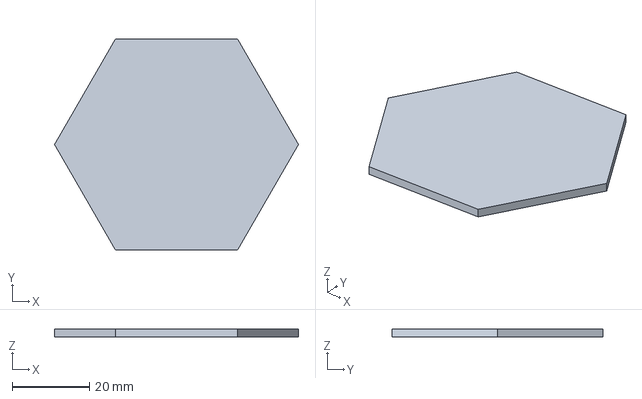
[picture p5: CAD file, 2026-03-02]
mechanic/Top.FCStd
63.2 x 54.7 x 2.00 mm

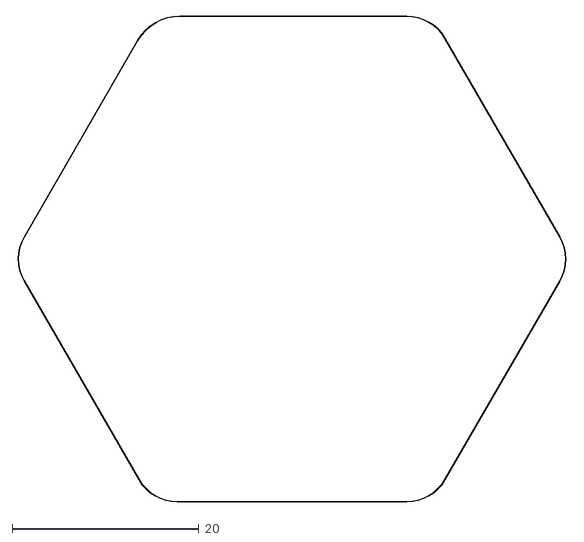
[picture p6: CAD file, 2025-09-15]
mechanic/PcbBoard-Body.dxf
59.0 x 52.0

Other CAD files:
mechanic/PcbBoard.FCStd
mechanic/Bottom-Body.stl
mechanic/Top-Body.stl

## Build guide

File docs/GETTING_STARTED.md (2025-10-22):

<!--
SPDX-FileCopyrightText: 2025 hexaTune LLC
SPDX-License-Identifier: MIT
-->

# 🚀 Getting Started with hexaGenMini

Welcome to the hexaGenMini project! This guide will help you set up your development environment, build the project components, and get started with contributing or using hexaGenMini.

## Prerequisites

Before you begin, ensure you have the following installed:

- **Git**: For version control
- **Node.js** and **pnpm**: For managing development tools
- **Rust**: For firmware development (install via rustup)
- **KiCad**: For PCB design (optional, for hardware development)
- **FreeCAD**: For mechanical design (optional, for enclosure design)
- **picotool**: For flashing firmware to Raspberry Pi Pico

## Project Setup

1. **Clone the repository**:
   ```bash
   git clone https://github.com/hTuneSys/hexaGenMini.git
   cd hexaGenMini
   ```

2. **Install dependencies**:
   ```bash
   pnpm install
   ```

3. **Set up pre-commit hooks**:
   ```bash
   pnpm prepare
   ```

## Development Areas

### Firmware Development

The firmware is written in Rust for the RP2040 microcontroller.

1. **Navigate to firmware directory**:
   ```bash
   cd firmware
   ```

2. **Install Rust targets** (if not already installed):
   ```bash
   rustup target add thumbv6m-none-eabi
   ```

3. **Connect your hexaGenMini device** via USB and put it in BOOTSEL mode (hold BOOTSEL button while plugging in).

4. **Flash and test the firmware**:
   ```bash
   cargo run
   ```

   This will build the firmware and flash it to the connected device.

5. **Monitor output** (optional):
   Use a tool like `minicom` or the embedded debugger to view serial output.

### Hardware Development

PCB designs are created with KiCad.

1. **Open KiCad** and load the project:
   - Navigate to `hardware/hexaGenMini-v1/`
   - Open `hexaGenMini-v1.kicad_pro`

2. **View schematics**:
   - Open `hexaGenMini-v1.kicad_sch`

3. **View PCB layout**:
   - Open `hexaGenMini-v1.kicad_pcb`

4. **Generate fabrication files**:
   - Use KiCad's Plot and Drill tools to export Gerber files
   - Fabrication outputs are pre-generated in `fabrication_output/`

### Mechanical Development

Enclosure designs are created with FreeCAD.

1. **Open FreeCAD** and load the design files:
   - `mechanic/Bottom.FCStd` - Bottom case
   - `mechanic/PcbBoard.FCStd` - PCB mounting

2. **Export for manufacturing**:
   - Use FreeCAD's export tools for STL (3D printing) or DXF (laser cutting)

## Testing Your Setup

1. **Firmware**: After flashing, the device should blink its status LED and be detectable as a USB MIDI device.

2. **AT Commands**: Use a MIDI tool to send SysEx messages with AT commands (see [ARCHITECTURE](ARCHITECTURE.md) for details).

3. **Hardware**: Verify PCB connections and component placement.

## Documentation

For more detailed information, explore the documentation files:

- [ARCHITECTURE](ARCHITECTURE.md) - System design and AT command protocol
- [DEVELOPMENT_GUIDE](DEVELOPMENT_GUIDE.md) - Detailed development setup
- [PROJECT_STRUCTURE](PROJECT_STRUCTURE.md) - Repository organization
- [CONTRIBUTING](CONTRIBUTING.md) - How to contribute
- [FAQ](FAQ.md) - Common questions

---

## 📚 Next Steps

- Check [ARCHITECTURE](ARCHITECTURE.md) to understand system design
- Review [CONTRIBUTING](CONTRIBUTING.md) to contribute effectively

---

You're now ready to explore and build with hexaGenMini. Happy hacking!

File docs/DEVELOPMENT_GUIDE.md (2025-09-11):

<!--
SPDX-FileCopyrightText: 2025 hexaTune LLC
SPDX-License-Identifier: MIT
-->

# DEVELOPMENT_GUIDE.md

This guide helps developers understand how to work with the hexaGenMini project. It explains the internal structure, tools, development workflow, and best practices.

---

## 🔀 Branching & PRs

Follow the naming rules defined in [BRANCH_STRATEGY](BRANCH_STRATEGY.md) and [PR_STRATEGY](PR_STRATEGY.md). Allowed branch prefixes:

- `feat/`, `fix/`, `refactor/`, `test/`, `docs/`, `ci/`, etc.

Create a feature branch:

```bash
git checkout -b feat/new-module
```

Open a PR with a valid title and follow checklist from [PULL_REQUEST_TEMPLATE](../.github/PULL_REQUEST_TEMPLATE.md).

---

## 🧱 Commit Conventions

Use the supported 12 types from [COMMIT_STRATEGY](COMMIT_STRATEGY.md). Example:

```bash
feat: add token parsing logic
```

Use semantic and meaningful commits. PRs with vague or mixed commits will be rejected.

---

## 🧪 CI/CD Pipeline

CI runs automatically via GitHub Actions:

- Linting (`clippy`)
- Formatting (`rustfmt`)
- Tests (`cargo test`)
- Branch and commit validation

---

## 🛡️ Branch Protection

Branches like `main`, `release`, and `develop` are protected:

- Require PR review
- Require status checks
- Require conventional commit title

---

## 📚 Documentation & Contributions

All contributors must follow the documentation style and structure:

- Use `///` for public Rust docs
- Update relevant `.md` files in `docs/` when modifying features
- Follow the guide in [CONTRIBUTING](CONTRIBUTING.md)

---

## 🧠 Helpful Resources

- [GETTING_STARTED](GETTING_STARTED.md) – Initial setup and quick commands
- [ARCHITECTURE](ARCHITECTURE.md) – System design and modules
- [CONTACT](CONTACT.md), [SUPPORT](SUPPORT.md) – Communication channels
- [LABELLING_STRATEGY](LABELLING_STRATEGY.md) – Tag issues/PRs correctly
- [PROJECT_STRUCTURE](PROJECT_STRUCTURE.md) – Directory structure
- [BRANCH_STRATEGY](BRANCH_STRATEGY.md) – Branch naming conventions
- [COMMIT_STRATEGY](COMMIT_STRATEGY.md) – Commit message conventions

---

Welcome to the hexaGenMini dev team! Let’s build it right from the start.

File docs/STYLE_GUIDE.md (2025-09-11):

<!--
SPDX-FileCopyrightText: 2025 hexaTune LLC
SPDX-License-Identifier: MIT
-->

# STYLE_GUIDE.md

This style guide ensures consistency across the codebase by outlining formatting rules, naming conventions, and Rust-specific practices used in the hexaGenMini project.

---

Consistent style improves collaboration and makes onboarding easier. Stick to this guide for clean, professional code.

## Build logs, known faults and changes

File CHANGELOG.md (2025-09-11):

# Changelog

All notable changes to this project will be documented in this file.

The format is based on [Keep a Changelog](https://keepachangelog.com/en/1.0.0/).

---

## [Unreleased]

### Added (Unreleased)

- Initial setup of hexaGenMini project structure.

### Changed

- Placeholder for upcoming changes.

### Fixed

- Placeholder for bug fixes.

---

## [0.0.0] - YYYY-MM-DD

### Added

- Project creation and initial commit.

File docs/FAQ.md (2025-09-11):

<!--
SPDX-FileCopyrightText: 2025 hexaTune LLC
SPDX-License-Identifier: MIT
-->

# FAQ.md

Frequently Asked Questions (FAQ) about the hexaGenMini project. If you have a question not listed here, feel free to open a GitHub Discussion or an Issue.

---

## ❓ How do I get started?

Refer to the [GETTING_STARTED](GETTING_STARTED.md) file (coming soon). It will walk you through setup, commands, and examples.

---

## ❓ How can I contribute?

Check out the [CONTRIBUTING](CONTRIBUTING.md) for instructions on how to suggest changes, report issues, and submit pull requests.

---

## ❓ Are there any requirements before contributing?

Yes. You must:

- Follow the commit message strategy defined in [COMMIT_STRATEGY](COMMIT_STRATEGY.md)
- Respect the branching and PR rules
- Adhere to the code of conduct

---

## ❓ What if I find a bug?

Open an issue using the [Bug Report Template](https://github.com/hTuneSys/hexaGenMini/issues/new?template=bug-report.md) and provide as much detail as possible.

---

## ❓ What should I do if I have a feature idea?

Use the [Feature Request Template](https://github.com/hTuneSys/hexaGenMini/issues/new?template=feature-request.md) or start a discussion to propose your idea.

---

## ❓ How is this project licensed?

hexaGenMini is licensed under the MIT License. See the [LICENSE](https://github.com/hTuneSys/hexaGenMini/blob/main/LICENSE) file for more details.

---

## ❓ Who maintains this project?

The project is maintained by the community, led by (Husamettin ARABACI). Maintainers and contributors are listed in the GitHub repository.

---

## ❓ How can I get help?

You can:

- Open a GitHub Discussion
- File an issue using the Support template
- Refer to the [SUPPORT](SUPPORT.md) and [CONTACT](CONTACT.md) files

---

Still have questions? Create a new discussion or join the community — we're happy to help!

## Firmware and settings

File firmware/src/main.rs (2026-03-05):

// SPDX-FileCopyrightText: 2025 hexaTune LLC
// SPDX-License-Identifier: MIT

#![no_std]
#![no_main]

use defmt::*;
use embassy_sync::blocking_mutex::raw::CriticalSectionRawMutex as Cs;
use embassy_sync::channel::Channel;
use embassy_sync::mutex::Mutex as AsyncMutex;
use {defmt_rtt as _, panic_probe as _};

mod at;
mod channel;
mod dds;
mod error;
mod hexa_config;
mod rgb;
mod usb;

use crate::channel::*;
pub const CAP: usize = 16;
pub static USB_CH: Channel<Cs, Msg, CAP> = Channel::new();
pub static AT_CH: Channel<Cs, Msg, CAP> = Channel::new();
pub static RGB_CH: Channel<Cs, Msg, CAP> = Channel::new();
pub static DDS_CH: Channel<Cs, Msg, CAP> = Channel::new();

embassy_rp::bind_interrupts!(struct IrqUsb {
    USBCTRL_IRQ => embassy_rp::usb::InterruptHandler<embassy_rp::peripherals::USB>;
});
embassy_rp::bind_interrupts!(struct IrqPio {
    PIO0_IRQ_0 => embassy_rp::pio::InterruptHandler<embassy_rp::peripherals::PIO0>;
});

#[embassy_executor::main]
async fn main(spawner: embassy_executor::Spawner) {
    //Initialize the RP2040
    let p = embassy_rp::init(Default::default());
    info!("Starting hexaGenMini firmware");

    //USB module
    info!("Initializing USB");
    let driver = embassy_rp::usb::Driver::new(p.USB, IrqUsb);
    let usb::UsbMidi { device, midi } = usb::init(driver);

    static MIDI_CELL: static_cell::StaticCell<AsyncMutex<Cs, usb::MyMidiClass<'static>>> =
        static_cell::StaticCell::new();
    let midi_mutex: &'static AsyncMutex<Cs, usb::MyMidiClass<'static>> =
        MIDI_CELL.init(AsyncMutex::new(midi));

    //AT module
    info!("Initializing AT command dispatcher");

    //Led module
    info!("Initializing RGB LED");
    let embassy_rp::pio::Pio {
        mut common, sm0, ..
    } = embassy_rp::pio::Pio::new(p.PIO0, IrqPio);
    let program = embassy_rp::pio_programs::ws2812::PioWs2812Program::new(&mut common);
    let ws2812 = embassy_rp::pio_programs::ws2812::PioWs2812::new(
        &mut common,
        sm0,
        p.DMA_CH0,
        p.PIN_23,
        &program,
    );
    let rgb_led = rgb::RgbLed::new(ws2812);

    //DDS module
    let ad9850 = dds::Ad985x::new(
        embassy_rp::gpio::Output::new(p.PIN_2, embassy_rp::gpio::Level::Low),
        embassy_rp::gpio::Output::new(p.PIN_3, embassy_rp::gpio::Level::Low),
        embassy_rp::gpio::Output::new(p.PIN_4, embassy_rp::gpio::Level::Low),
        embassy_rp::gpio::Output::new(p.PIN_5, embassy_rp::gpio::Level::Low),
        125_000_000,
        0,
    );

    //Dummy Led
    let led = embassy_rp::gpio::Output::new(p.PIN_25, embassy_rp::gpio::Level::Low);

    spawner.spawn(at::at_task(spawner)).unwrap();
    spawner.spawn(rgb::rgb_task(rgb_led)).unwrap();
    spawner.spawn(usb::dev_task(device)).unwrap();
    spawner.spawn(usb::usb_io_task(midi_mutex)).unwrap();
    spawner.spawn(dds::dds_task(ad9850)).unwrap();
    spawner.spawn(main_loop_task(led)).unwrap();
}

#[embassy_executor::task]
pub async fn main_loop_task(mut led: embassy_rp::gpio::Output<'static>) {
    //Dummy task to blink the LED
    loop {
        info!("Blink!");

        if hexa_config::is_dds_available() {
            led.set_high();
            embassy_time::Timer::after_secs(5).await;
            led.set_low();
            embassy_time::Timer::after_secs(5).await;
        } else {
            for _ in 0..50 {
                led.set_high();
                embassy_time::Timer::after_millis(100).await;
                led.set_low();
                embassy_time::Timer::after_millis(100).await;
            }
        }
    }
}

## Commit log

2025-09-11 Add base schematic for hardware
    [CONNECTOR.kicad_sch, DDS.kicad_sch, LDO.kicad_sch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]
2025-09-15 Finish first hardware basic
    [CONNECTOR.kicad_sch, DDS.kicad_sch, LDO.kicad_sch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]
2025-09-21 feat(config): Add default config for github (#8)
    .github docs and reuse config is added for init
    [Bottom.FCStd, hexaGenMini-v1.step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]
2025-09-26 Added Bottom Plate
    [Bottom.FCStd]
2025-10-26 feat(multicore): fixed multicore
    Fixed channel for multicore tasks
    [main_multicore.rs]
2026-03-02 fix(hotfix): basic fix
    [Bottom-Body.stl, Bottom.FCStd, PcbBoard.FCStd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]
2026-03-04 feat(firmware): migrate AT/SysEx/USB-MIDI to hexaTuneProto shared library (#39)
    Replace hand-written AT command parser, SysEx framing, and USB MIDI
    packetization with hexa-tune-proto and hexa-tune-proto-embedded crates
    to establish a unified protocol layer shared between embedded firmware
    and Flutter mobile app.
    Changes:
    - Add hexa-tune-proto and hexa-tune-proto-embedded path dependencies
    - Remove unused sha2 and base64 dependencies
    - Replace Error enum with FirmwareError wrapper (Proto/Hexa/firmware)
    - Replace AtCommand-based Msg enum with typed variants (RgbSet, FreqSet, etc.)
    - Delete sysex/mod.rs — replaced by hexa_tune_proto::sysex
    - Delete at/command.rs — replaced by hexa_tune_pro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
    [main.rs]
2026-03-05 chore(firmware): switch hexa-tune-proto deps from local path to crates.io v0.1.1
